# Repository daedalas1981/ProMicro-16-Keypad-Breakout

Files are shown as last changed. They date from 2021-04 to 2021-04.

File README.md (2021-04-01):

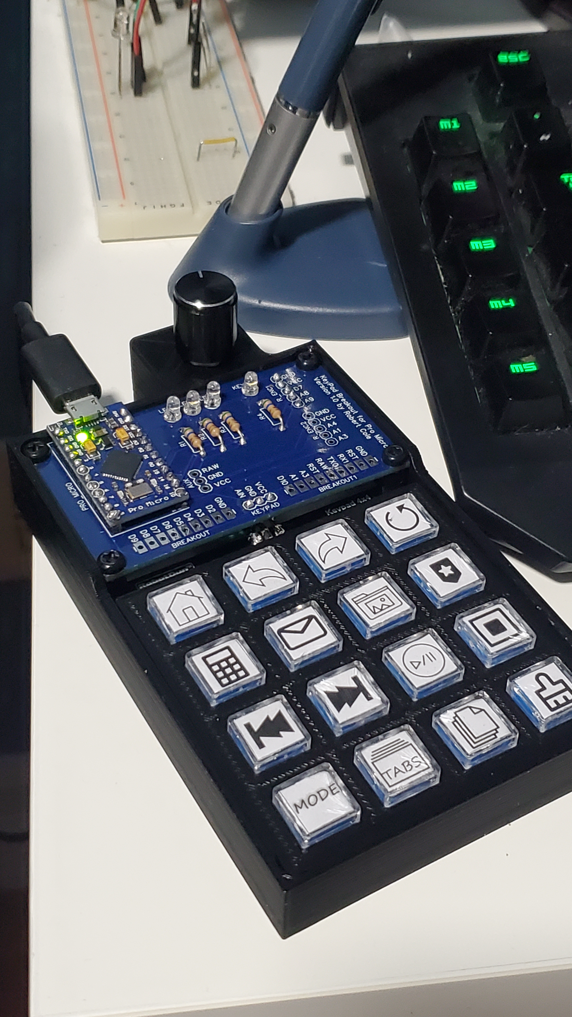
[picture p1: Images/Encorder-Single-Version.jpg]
Single Encoder
**Single Encoder**  or **Dual Encoder** Dual Encoder
# KeyPad Breakout for Pro Micro and RobotDyn Keypad
## Required components:
- Arduino Pro Micro 32U Microcontroller.
- NicoHood's HID-Project Library for Arduino. [HID-Project](https://github.com/NicoHood/HID)
- RobotDyn 16 button 3-wire keypad. [RobotDyn 4x4 Keypad](https://robotdyn.com/button-keypad-4x4-module.html) / [Banggood - RobotDyn 4x4 Keypad](https://www.banggood.com/5V-Button-Keypad-4x4-Module-Assembled-Keyboard-p-1645007.html)
- Keypad Breakout for Pro Micro ver1.0 by Robert.
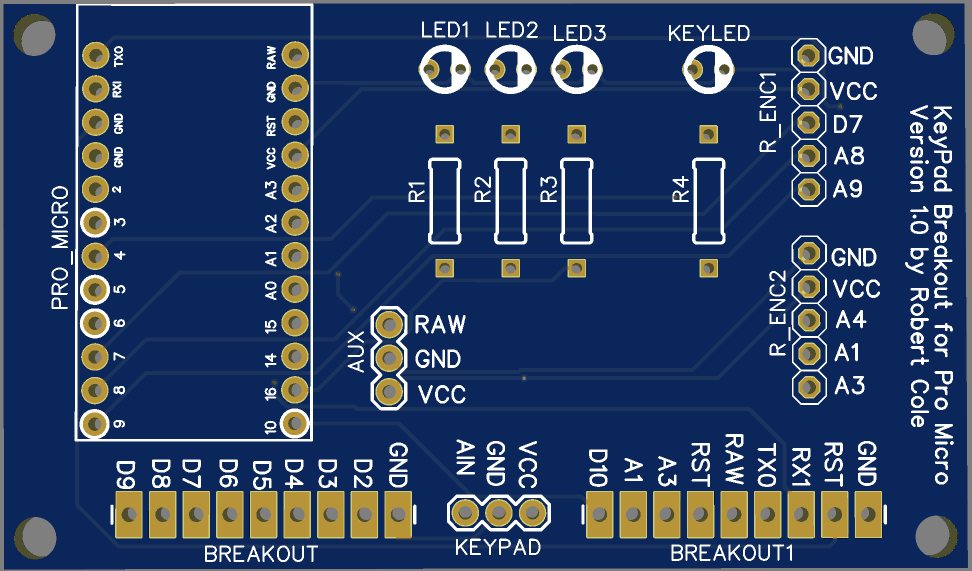
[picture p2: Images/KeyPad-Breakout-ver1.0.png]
KeyPad Breakout


## Optional (but recommended):
- One or Two Dual Encoders with presoldered resistors. [Amazon - Cylewet 5Pcs KY-040 Rotary Encoder Module with 15×16.5 mm with Knob Cap for Arduino](https://www.amazon.ca/dp/B07DFFSZ73/ref=cm_sw_em_r_mt_dp_GTFJT82QA5BB0PV9Z99V?_encoding=UTF8&psc=1)
- (4) 3mm LEDS. (I used white generic. Will determine resistors req'd).
- (4) 5.6ohm resistors. (or appropriate  for your LEDS).
- Male to Female Leads.
- 3D Printed Case. (or maybe a suitable wood case?).
- Printer / Printed labels for the keypad.
- (6) M3 Screws and Nuts. [Screws / Nuts / Standoffs](https://www.amazon.ca/gp/product/B06Y591NKK/ref=ppx_yo_dt_b_asin_title_o04_s01?ie=UTF8&psc=1)
- (2) M3 x 8mm Standoffs.

## Folder Structure
- **Arduino**, contains .INO for Arduino IDE. Requires HID-Project.h Library (GitHub) and Encoder.h (Library Manager in IDE)
- **EasyEDA**, contains .JSON files for EasyEDA to create PCB for the breakout board. Can be sent to board manufacturer.
- **Fusion360**, contains both .F3D and .STL files. The .F3D files can be changed to your neeeds. The .STL can be sent to a 3D printed if using the same components.
- **Images**, Self-explanatory.
- **KeyMap**, contains a text file with the default key mapping when using the configured settings in the .INO file for Arduino. I use it as a cheat sheet.
- **RobotDyn**, contains files for measurements and schematics for the keypad.
- **Schematics**, contains all the diagrams, pictures, and schematics of the project.

# Description
I wanted to turn a keypad into a functional macro keyboard. In order to maximize the use of the keyboard, I created a MODE button that allows up to 4 button layouts that can be toggled between. Using the HID-Project Library, the first mode focuses on common shortcuts, web broswers, and operating systems. MODES 2-4 focus on the use of F13-F24 keys not normally found on standard keyboards allowing unique bindings for different applications.

One of the best features is pairing this project with one or two encoders. I have programmed them by default as being one dedicated to Volume Up and Down with the press to Mute. The second encoder has been set to be a Zoom In and Out with the press to Reset to 100%. Perfect for Photoshop, or even Web browsing,

**Noteworthy code for the encoders:** 4x4-KeyPad-Multi.ino
```
// ENCODER SETUP
bool encoderOneEnable = true; // DEFAULT ENCODER on R_ENC1
bool encoderTwoEnable = true; // SECONDARY ENCODER on R_ENC2
```
*These settings will enable or disable the encoders.*

I also left many pin outs for possible future use or variations when designing the circuit board. As of version 1.0, I can say everything is working! However, like everything when prototyping, I should have chose my pins more wisely for the LEDs. It would have been nice to set a dimmer for them. Three of the LEDs display the Mode. All off is mode 1, left LED is mode 2, middle LED is mode 3, and the right LED is mode 4. They all stay on while in their respective mode. The fourth LED is a keypress confirmation. Briefly lights while the key is pressed, and turns off when released.

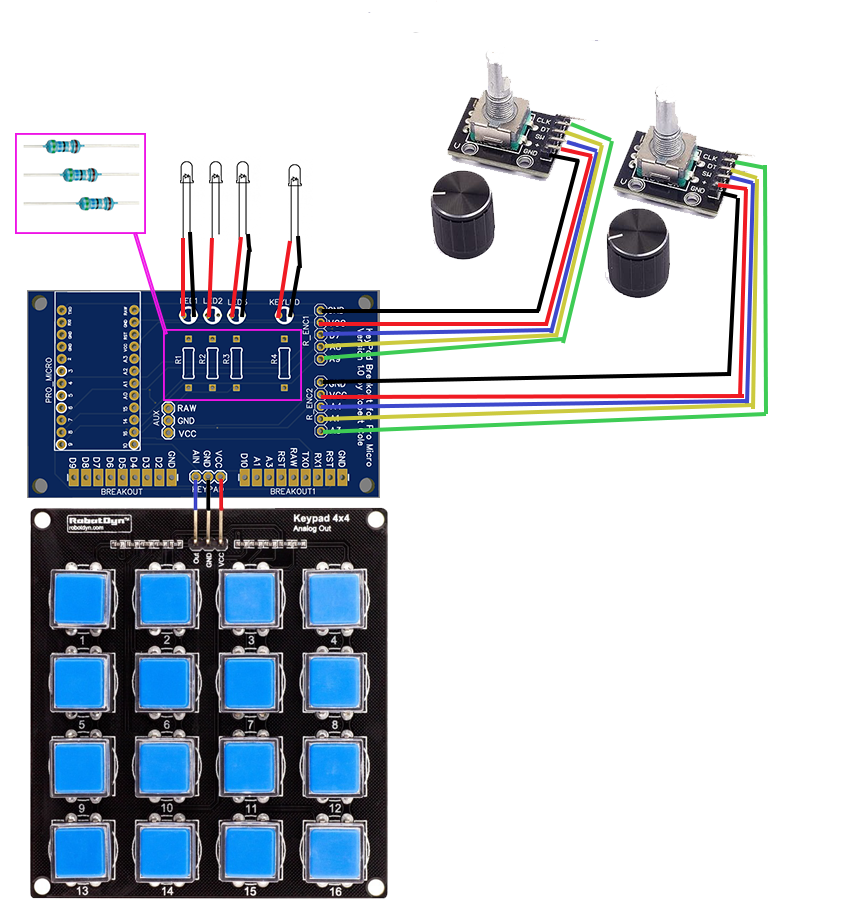
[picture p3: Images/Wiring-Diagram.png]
Wiring Diagram


# Friendly Words
This is my first public project. I'm fairly new to creating content on GitHub. I have been programming for awhile. The project case I created using Fusion 360, and printed on an AnyCubic Mega Pro. The circuit board was created using EasyEDA. It was the first time I created a circuit board and had it printed via PCBWay as they do small batches for cheap at the time of writing this. Many thanks to snippets of code and hours of mistakes to get the code to where it is today from countless people I found on internet searches. NicoHood's HID-Project was the final touch required to make this project possible. Please leave me a comment if something is not right, or can be changed, or if I've done something wrong. Thanks!

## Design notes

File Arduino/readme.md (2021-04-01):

# Arduino

## Arduino Pro Micro Version
In order for the RobotDyn 4x4 KeyPad to read the values from the analog output, the 5V-16 MHz version of the board must be used.

## Arduino Pro Micro Leonardo
The firmware / IDE settings need to be the Leonardo. This is so the device can broadcast itself over USB as a HID device. (Human Interface Device). It will show up in Windows as a Leonardo USB HID Device.

## Arduino IDE / INO
Please note the SETUP for the Encoders. Change as needed for One or Two.
```
// ENCODER SETUP
bool encoderOneEnable = true; // DEFAULT ENCODER on R_ENC1
bool encoderTwoEnable = true; // SECONDARY ENCODER on R_ENC2
```
Also the pinouts are set for use with the breakout board. Change what suits your needs.

## Key Mapping
The .INO file is broken into 4 CASES. Each Case has 16 key mappings.
- Case 0 - 15 Keys + 1 Mode Key - Mode 1 - Default - System Macros
- Case 1 - 15 Keys + 1 Mode Key - Mode 2 -  Unique Left Control + F13-F24 Keys + Copy / Paste
- Case 2 - 15 Keys + 1 Mode Key - Mode 3 -  F13-F24 Keys + Copy / Paste
- Case 3 - 15 Keys + 1 Mode Key - Mode 4 -  F1-F12 Keys + Save/Close/Quit

Create combinations of KeyPresses, but just remember to release them again!
```
KeyPress.releaseALL();
```

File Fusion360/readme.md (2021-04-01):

# Single vs Dual Encoder
I found using dual encoders to help with many of the projects I was working on. A single encoder is great for volume up and down.

## Some Ideas for a 2nd Encoder
- Microphone Volume up and down / Press to Mute. (Custom Mapping req'd.)
- Zoom In and Out / Press to Reset. (Ctrl+, Ctrl-, Ctrl 0)
- Scroll Up and Down / Press to Home or End. (Page Up, Page Down, Home/End)
- Scrub Left and Right / Press Enter. (Left arrow, Right arrow, Enter)
- Add/Subtract Values / Press to Enter. ((+1 Enter),(-1 Enter), Enter) <- Using 1 as an increment example.
- Fast Forward / Rewind / Play/Pause. (FF,Rewind,Play/Pause)
- Cycle thru Open Windows / Press to Open.
- Cycle thru Browser Tabs.
- Use the 2nd Encoder Press for Mode Switching allowing an addtional key (Key 13) for assignment.

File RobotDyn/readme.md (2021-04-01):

Using Photoshop you can change or create your own printable Icons. The Squares are 11.8mm x 11.8mm. I created them at 12mm x 12mm and cut the black line so that it was not visible and fit perfectly in the clear key caps.

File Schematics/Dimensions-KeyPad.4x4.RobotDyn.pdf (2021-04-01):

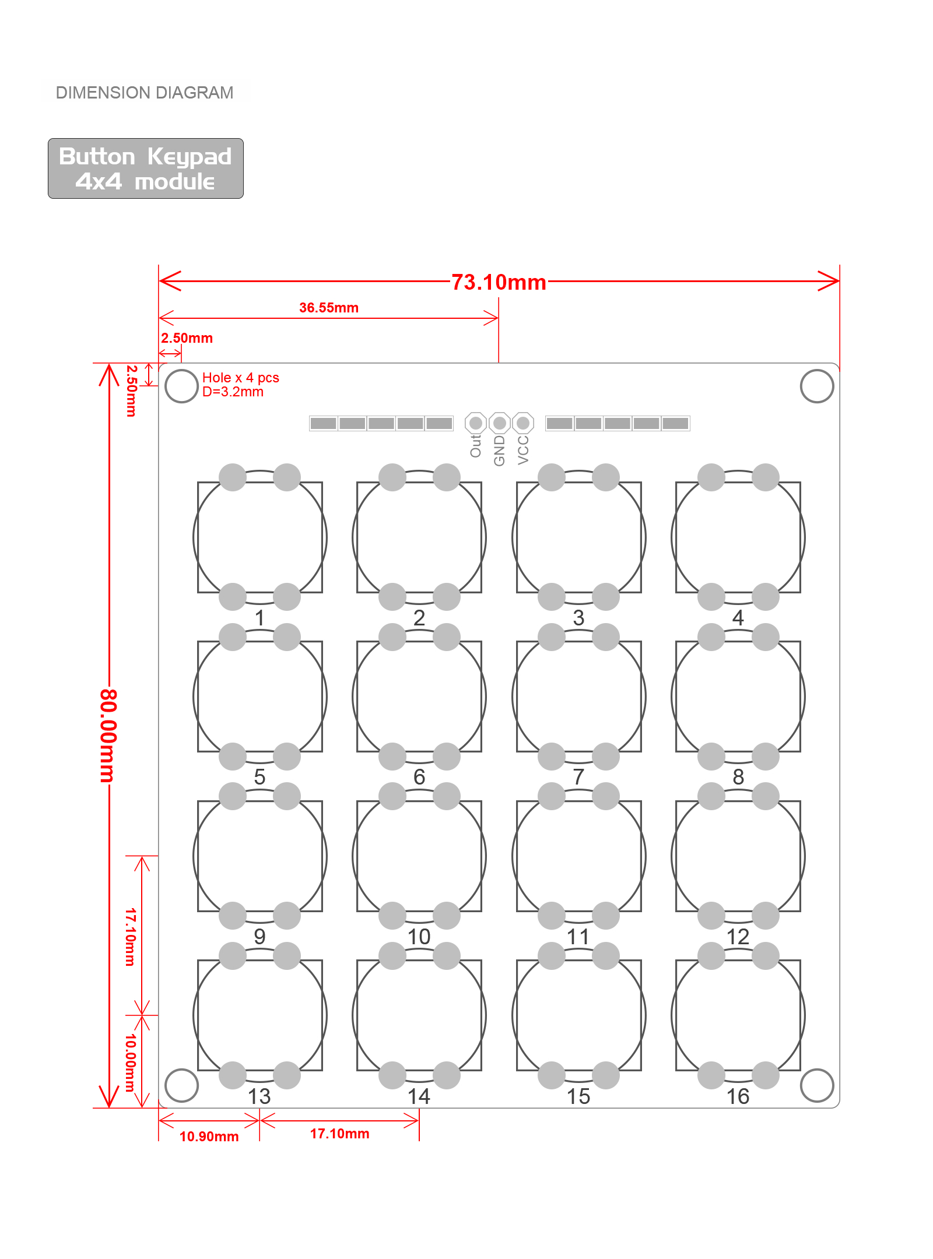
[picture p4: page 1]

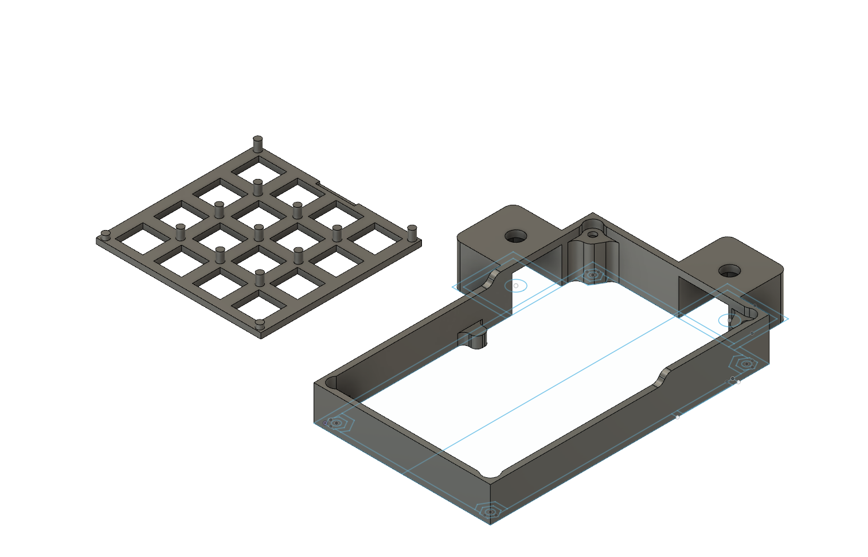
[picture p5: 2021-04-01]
Schematics/DUAL Encoder v1.png

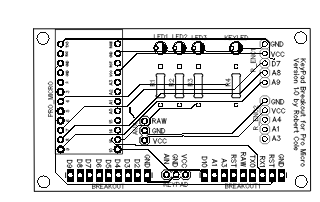
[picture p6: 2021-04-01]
Schematics/PCB_Layout-Keypad.Breakout.ver1.0.png

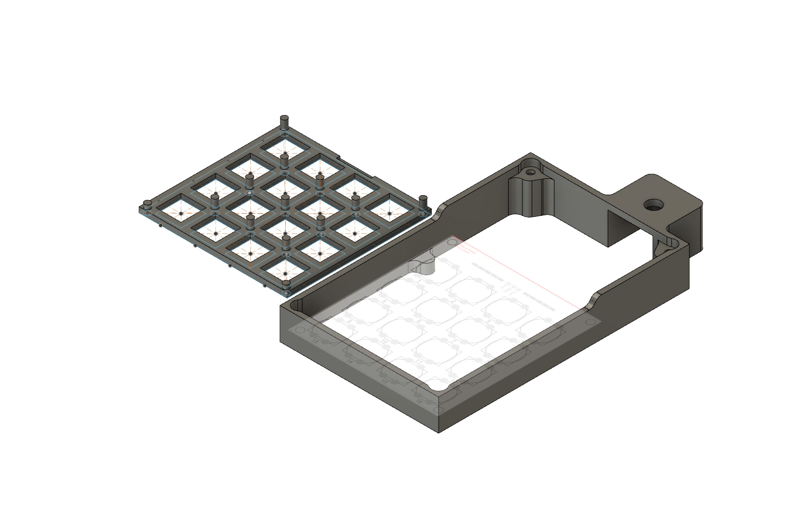
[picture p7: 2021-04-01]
Schematics/Single Encoder.png

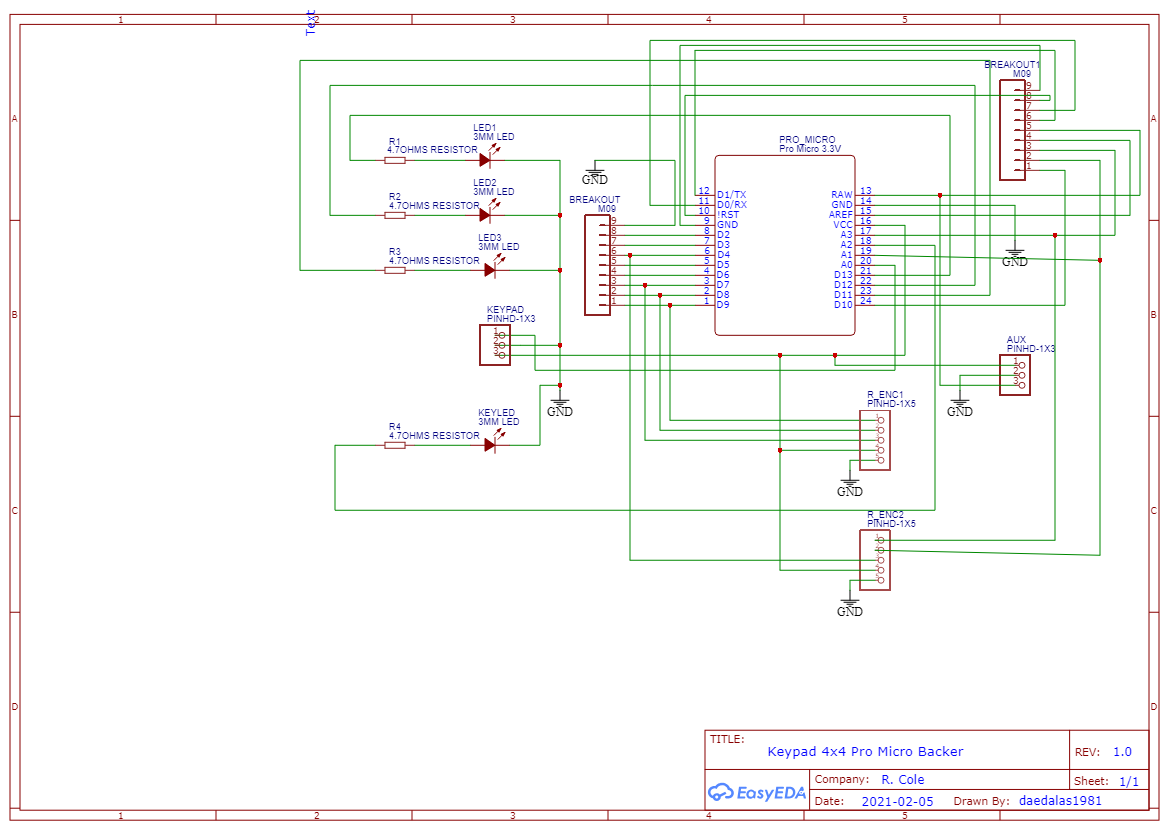
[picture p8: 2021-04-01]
Schematics/Schematic_4x4 Keypad_2021-03-31.png

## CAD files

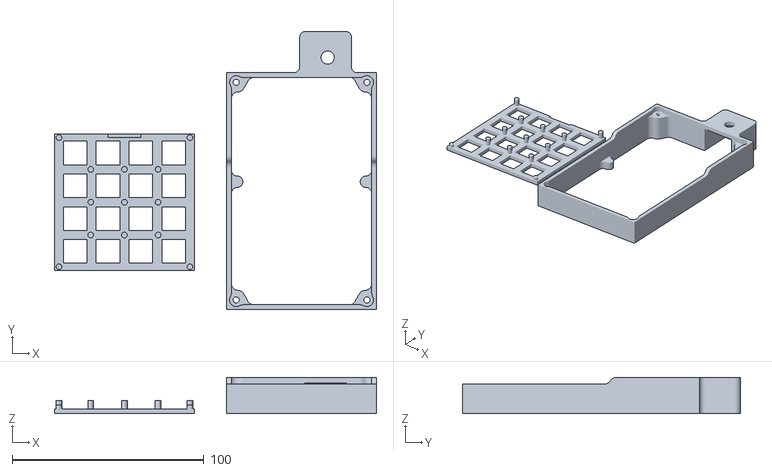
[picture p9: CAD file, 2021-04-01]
Fusion360/Single Encoder.stl
167.8 x 144.9 x 19.0

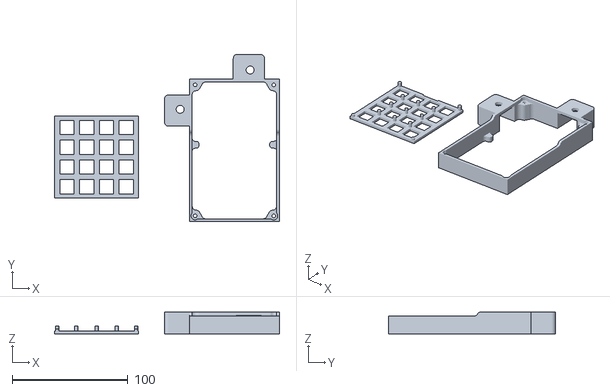
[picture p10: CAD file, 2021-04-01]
Fusion360/DUAL Encoder.stl
194.8 x 144.9 x 19.0

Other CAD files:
Fusion360/DUAL Encoder.f3d
Fusion360/SINGLE Encoder.f3d

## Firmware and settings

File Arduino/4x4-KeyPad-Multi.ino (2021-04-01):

///////////////////////////////////////////////
// RobotDyn Keypad 4x4 Macro Script ver1.0  //
/********************************************
// Arduino Pro Micro
// 3-Wire Connection
// ~ Data Pin on A0
// ~ Power 5V on VCC
// ~ Ground on GND
//
// KeyPad Breakout for Pro Micro v1.0 by Robert Cole
***********************************/
// Created by Robert Cole

// KEY REFERENCE GUIDE
/*
KEY_LEFT_CTRL
KEY_LEFT_SHIFT
KEY_LEFT_ALT
KEY_LEFT_GUI
KEY_RIGHT_CTRL
KEY_RIGHT_SHIFT
KEY_RIGHT_ALT
KEY_RIGHT_GUI
KEY_UP_ARROW
KEY_DOWN_ARROW
KEY_LEFT_ARROW
KEY_RIGHT_ARROW
KEY_BACKSPACE
KEY_TAB
KEY_RETURN
KEY_ESC
KEY_INSERT
KEY_DELETE
KEY_PAGE_UP
KEY_PAGE_DOWN
KEY_HOME
KEY_END
KEY_CAPS_LOCK
KEY_F1
KEY_F2
KEY_F3
KEY_F4
KEY_F5
KEY_F6
KEY_F7
KEY_F8
KEY_F9
KEY_F10
KEY_F11
KEY_F12
KEY_F13
KEY_F14
KEY_F15
KEY_F16
KEY_F17
KEY_F18
KEY_F19
KEY_F20
KEY_F21
KEY_F22
KEY_F23
KEY_F24

*** CONSUMER.WRITE KEY LIST ***

MEDIA_FAST_FORWARD
MEDIA_REWIND
MEDIA_NEXT
MEDIA_PREVIOUS
MEDIA_STOP
MEDIA_PLAY_PAUSE

MEDIA_VOLUME_MUTE
MEDIA_VOLUME_UP
MEDIA_VOLUME_DOWN

CONSUMER_EMAIL_READER
CONSUMER_CALCULATOR
CONSUMER_EXPLORER

CONSUMER_BROWSER_HOME
CONSUMER_BROWSER_BACK
CONSUMER_BROWSER_FORWARD
CONSUMER_BROWSER_REFRESH
CONSUMER_BROWSER_BOOKMARKS

*/

// Include HID-Project by NicoHood - Keyboard Library
#include <HID-Project.h>

// Include Encorder Library
#include <Encoder.h>

// Analog Data Pin = Pin A0 or Pin 18 FOR RobotDyn 4x4 (3-wire) KEYPAD / AIN->OUT
const int buttonPin = A0;

// On Press Button Flash LED
const int flashLED = A2;

// LED MODE Indicator Pins
const int MODE1 = 15;
const int MODE2 = 14;
const int MODE3 = 16;
int  currentMode = 0;

// ENCODER SETUP
bool encoderOneEnable = true; // DEFAULT ENCODER on R_ENC1
bool encoderTwoEnable = true; // SECONDARY ENCODER on R_ENC2

// ENCODER 1 SETUP
const int buttonMute = 7; // MUTE BUTTON / Switch Pin

Encoder knobVol(8, 9);  // VOLUME KNOB

int stateVol = 0;
long volValue  = -999;

// ENCODER 2 SETUP
const int buttonMuteTWO = 4; // MUTE BUTTON / Switch Pin

Encoder knobVolTWO(19, 21);  // VOLUME KNOB / Second Encoder

int stateVolTWO = 0;
long volValueTWO  = -999; 

// Get KeyPaD Analog Value
int get_button(int val) {
 // Lets get the Current Mode to Decide Which Macro Layout to Use
 switch(currentMode){
 // DEFAULT LAYOUT
 
 // MODE 1 SETUP ******************************************
 case 0:
  // get analog input value
 if(val>1000){
    Consumer.write(CONSUMER_BROWSER_HOME);
    delay(200);
    return 1;
 }
 else if(val>900){
    Consumer.write(CONSUMER_BROWSER_BACK);
    delay(200);
    return 2;
 }
 else if(val>820){
    Consumer.write(CONSUMER_BROWSER_FORWARD);
    delay(200);
    Keyboard.releaseAll();
    return 3;
 }
 else if(val>750){
    Consumer.write(CONSUMER_BROWSER_REFRESH);
    delay(200);
    return 4;
 }
 else if(val>660){
    Consumer.write(CONSUMER_CALCULATOR);
    delay(200);
    return 5;
 }
 else if(val>620){
    Consumer.write(CONSUMER_EMAIL_READER);
    delay(200);
    return 6;
 }
 else if(val>585){
    Consumer.write(CONSUMER_EXPLORER);
    delay(200);
    return 7;
 }
 else if(val>540){
    Keyboard.press(KEY_LEFT_CTRL); //Presses the CTRL key.
    Keyboard.press(KEY_LEFT_SHIFT); //Presses the CTRL key.
    Keyboard.press('o'); //Presses the F16 key.
    delay(200);
    Keyboard.releaseAll();
    return 8;
 }
 else if(val>500){
    Consumer.write(MEDIA_PREVIOUS);
    delay(200);
    return 9;
 }
 else if(val>475){
    Consumer.write(MEDIA_NEXT);
    delay(200);
    return 10;
 }
 else if(val>455){
    Consumer.write(MEDIA_PLAY_PAUSE);
    delay(200);
    return 11;
 }
 else if(val>425){
    Consumer.write(MEDIA_STOP);
    delay(200);
    return 12;
 }
 else if(val>370){
    // Switch Mode Button on 13
    // Add 1 to the Current Mode
    currentMode++;
    if (currentMode == 4) {
      // RESET to 0 when MAX. 
      currentMode = 0;
    }
    switch_Mode(currentMode);
    delay(200);
    Keyboard.releaseAll();
    return 13;
 }
 else if(val>300){
    // Change TAB View
    Keyboard.press(KEY_LEFT_ALT); //Presses the LEFT ALT key.
    Keyboard.press(KEY_TAB); //Presses the TAB key.
    Keyboard.release(KEY_TAB); // Release Single Keypress.
    Keyboard.press(KEY_TAB); //Presses the TAB key.
    delay(200);
    Keyboard.releaseAll();
    return 14;
 }
 else if(val>260){
    // COPY
    Keyboard.press(KEY_LEFT_CTRL); //Presses the CTRL key.
    Keyboard.press('c'); //Presses the C key.
    delay(200);
    Keyboard.releaseAll();
    return 15;
 }
 else if(val>200){
    // PASTE
    Keyboard.press(KEY_LEFT_CTRL); //Presses the CTRL key.
    Keyboard.press('v'); //Presses the C key.
    delay(200);
    Keyboard.releaseAll();
    return 16;
 }
 else {
    return 0;
 }
    break;

// MODE 2 SETUP ******************************************   
 case 1:
 // get analog input value
 if(val>1000){
    Keyboard.press(KEY_LEFT_CTRL); //Presses the CTRL key.
    Keyboard.press(KEY_F13); //Presses the F13 key.
    delay(200);
    Keyboard.releaseAll();
    return 1;
 }
 else if(val>900){
    Keyboard.press(KEY_LEFT_CTRL); //Presses the CTRL key.
    Keyboard.press(KEY_F14); //Presses the F14 key.
    delay(200);
    Keyboard.releaseAll();
    return 2;
 }
 else if(val>820){
    Keyboard.press(KEY_LEFT_CTRL); //Presses the CTRL key.
    Keyboard.press(KEY_F15); //Presses the F15 key.
    delay(200);
    Keyboard.releaseAll();
    return 3;
 }
 else if(val>750){
    Keyboard.press(KEY_LEFT_CTRL); //Presses the CTRL key.
    Keyboard.press(KEY_F16); //Presses the F16 key.
    delay(200);
    Keyboard.releaseAll();
    return 4;
 }
 else if(val>660){
    Keyboard.press(KEY_LEFT_CTRL); //Presses the CTRL key.
    Keyboard.press(KEY_F17); //Presses the F17 key.
    delay(200);
    Keyboard.releaseAll();
    return 5;
 }
 else if(val>620){
    Keyboard.press(KEY_LEFT_CTRL); //Presses the CTRL key.
    Keyboard.press(KEY_F18); //Presses the F18 key.
    delay(200);
    Keyboard.releaseAll();
    return 6;
 }
 else if(val>585){
    Keyboard.press(KEY_LEFT_CTRL); //Presses the CTRL key.
    Keyboard.press(KEY_F19); //Presses the F19 key.
    delay(200);
    Keyboard.releaseAll();
    return 7;
 }
 else if(val>540){
    Keyboard.press(KEY_LEFT_CTRL); //Presses the CTRL key.
    Keyboard.press(KEY_F20); //Presses the F20 key.
    delay(200);
    Keyboard.releaseAll();
    return 8;
 }
 else if(val>500){
    Keyboard.press(KEY_LEFT_CTRL); //Presses the CTRL key.
    Keyboard.press(KEY_F21); //Presses the F21 key.
    delay(200);
    Keyboard.releaseAll();
    return 9;
 }
 else if(val>475){
    Keyboard.press(KEY_LEFT_CTRL); //Presses the CTRL key.
    Keyboard.press(KEY_F22); //Presses the F22 key.
    delay(200);
    Keyboard.releaseAll();
    return 10;
 }
 else if(val>455){
    Keyboard.press(KEY_LEFT_CTRL); //Presses the CTRL key.
    Keyboard.press(KEY_F23); //Presses the F23 key.
    delay(200);
    Keyboard.releaseAll();
    return 11;
 }
 else if(val>425){
    Keyboard.press(KEY_LEFT_CTRL); //Presses the CTRL key.
    Keyboard.press(KEY_F24); //Presses the F24 key.
    delay(200);
    Keyboard.releaseAll();
    return 12;
 }
 else if(val>370){
    // Switch Mode Button on 13
    // Add 1 to the Current Mode
    currentMode++;
    if (currentMode == 4) {
      // RESET to 0 when MAX. 
      currentMode = 0;
    }
    switch_Mode(currentMode);
    delay(200);
    Keyboard.releaseAll();
    return 13;
 }
 else if(val>300){
    // Change TAB View
    Keyboard.press(KEY_LEFT_ALT); //Presses the LEFT ALT key.
    Keyboard.press(KEY_TAB); //Presses the TAB key.
    Keyboard.release(KEY_TAB); // Release Single Keypress.
    Keyboard.press(KEY_TAB); //Presses the TAB key.
    delay(200);
    Keyboard.releaseAll();
    return 14;
 }
 else if(val>260){
    // COPY
    Keyboard.press(KEY_LEFT_CTRL); //Presses the CTRL key.
    Keyboard.press('c'); //Presses the C key.
    delay(200);
    Keyboard.releaseAll();
    return 15;
 }
 else if(val>200){
    // PASTE
    Keyboard.press(KEY_LEFT_CTRL); //Presses the CTRL key.
    Keyboard.press('v'); //Presses the C key.
    delay(200);
    Keyboard.releaseAll();
    return 16;
 }
 else {
    return 0;
 }
    break;
 
 // MODE3 SETUP ******************************************
  case 2:
  // ALTERNATE MODE 2
  // get analog input value
 if(val>1000){
    Keyboard.press(KEY_F13); //Presses the F13 key.
    delay(200);
    Keyboard.releaseAll();
    return 1;
 }
 else if(val>900){
    Keyboard.press(KEY_F14); //Presses the F14 key.
    delay(200);
    Keyboard.releaseAll();
    return 2;
 }
 else if(val>820){
    Keyboard.press(KEY_F15); //Presses the F15 key.
    delay(200);
    Keyboard.releaseAll();
    return 3;
 }
 else if(val>750){
    Keyboard.press(KEY_F16); //Presses the F16 key.
    delay(200);
    Keyboard.releaseAll();
    return 4;
 }
 else if(val>660){
    Keyboard.press(KEY_F17); //Presses the F17 key.
    delay(200);
    Keyboard.releaseAll();
    return 5;
 }
 else if(val>620){
    Keyboard.press(KEY_F18); //Presses the F18 key.
    delay(200);
    Keyboard.releaseAll();
    return 6;
 }
 else if(val>585){
    Keyboard.press(KEY_F19); //Presses the F19 key.
    delay(200);
    Keyboard.releaseAll();
    return 7;
 }
 else if(val>540){
    Keyboard.press(KEY_F20); //Presses the F20 key.
    delay(200);
    Keyboard.releaseAll();
    return 8;
 }
 else if(val>500){
    Keyboard.press(KEY_F21); //Presses the F21 key.
    delay(200);
    Keyboard.releaseAll();
    return 9;
 }
 else if(val>475){
    Keyboard.press(KEY_F22); //Presses the F22 key.
    delay(200);
    Keyboard.releaseAll();
    return 10;
 }
 else if(val>455){
    Keyboard.press(KEY_F23); //Presses the F23 key.
    delay(200);
    Keyboard.releaseAll();
    return 11;
 }
 else if(val>425){
    Keyboard.press(KEY_F24); //Presses the F24 key.
    delay(200);
    Keyboard.releaseAll();
    return 12;
 }
 else if(val>370){
    // Switch Mode Button on 13
    // Add 1 to the Current Mode
    currentMode++;
    if (currentMode == 4) {
      // RESET to 0 when MAX. 
      currentMode = 0;
    }
    switch_Mode(currentMode);
    delay(200);
    Keyboard.releaseAll();
    return 13;
 }
 else if(val>300){
    // Change TAB View
    Keyboard.press(KEY_LEFT_ALT); //Presses the LEFT ALT key.
    Keyboard.press(KEY_TAB); //Presses the TAB key.
    Keyboard.release(KEY_TAB); // Release Single Keypress.
    Keyboard.press(KEY_TAB); //Presses the TAB key.
    delay(200);
    Keyboard.releaseAll();
    return 14;
 }
 else if(val>260){
    // COPY
    Keyboard.press(KEY_LEFT_CTRL); //Presses the CTRL key.
    Keyboard.press('c'); //Presses the C key.
    delay(200);
    Keyboard.releaseAll();
    return 15;
 }
 else if(val>200){
    // PASTE
    Keyboard.press(KEY_LEFT_CTRL); //Presses the CTRL key.
    Keyboard.press('v'); //Presses the C key.
    delay(200);
    Keyboard.releaseAll();
    return 16;
 }
 else {
    return 0;
 }
    break;

 // MODE 4 SETUP ******************************************
  case 3:
  // ALTERNATE MODE 3
  // get analog input value
 if(val>1000){
    Keyboard.press(KEY_F1); //Presses the F13 key.
    delay(200);
    Keyboard.releaseAll();
    return 1;
 }
 else if(val>900){
    Keyboard.press(KEY_F2); //Presses the F14 key.
    delay(200);
    Keyboard.releaseAll();
    return 2;
 }
 else if(val>820){
    Keyboard.press(KEY_F3); //Presses the F15 key.
    delay(200);
    Keyboard.releaseAll();
    return 3;
 }
 else if(val>750){
    Keyboard.press(KEY_F4); //Presses the F16 key.
    delay(200);
    Keyboard.releaseAll();
    return 4;
 }
 else if(val>660){
    Keyboard.press(KEY_F5); //Presses the F17 key.
    delay(200);
    Keyboard.releaseAll();
    return 5;
 }
 else if(val>620){
    Keyboard.press(KEY_F6); //Presses the F18 key.
    delay(200);
    Keyboard.releaseAll();
    return 6;
 }
 else if(val>585){
    Keyboard.press(KEY_F7); //Presses the F19 key.
    delay(200);
    Keyboard.releaseAll();
    return 7;
 }
 else if(val>540){
    Keyboard.press(KEY_F8); //Presses the F20 key.
    delay(200);
    Keyboard.releaseAll();
    return 8;
 }
 else if(val>500){
    Keyboard.press(KEY_F9); //Presses the F21 key.
    delay(200);
    Keyboard.releaseAll();
    return 9;
 }
 else if(val>475){
    Keyboard.press(KEY_F10); //Presses the F22 key.
    delay(200);
    Keyboard.releaseAll();
    return 10;
 }
 else if(val>455){
    Keyboard.press(KEY_F11); //Presses the F23 key.
    delay(200);
    Keyboard.releaseAll();
    return 11;
 }
 else if(val>425){
    Keyboard.press(KEY_F12); //Presses the F24 key.
    delay(200);
    Keyboard.releaseAll();
    return 12;
 }
 else if(val>370){
    // Switch Mode Button on 13
    // Add 1 to the Current Mode
    currentMode++;
    if (currentMode == 4) {
      // RESET to 0 when MAX. 
      currentMode = 0;
    }
    switch_Mode(currentMode);
    delay(200);
    Keyboard.releaseAll();
    return 13;
 }
 else if(val>300){
    // SAVE BUTTON
    Keyboard.press(KEY_LEFT_CTRL); //Presses the CTRL key.
    Keyboard.press('s'); //Presses the C key.
    delay(200);
    Keyboard.releaseAll();
    return 14;
 }
 else if(val>260){
    // CLOSE CURRENT WINDOW WITHIN APPLICATION
    Keyboard.press(KEY_LEFT_CTRL); //Presses the CTRL key.
    Keyboard.press('w'); //Presses the C key.
    delay(200);
    Keyboard.releaseAll();
    return 15;
 }
 else if(val>200){
    // QUIT PROGRAM
    Keyboard.press(KEY_LEFT_CTRL); //Presses the CTRL key.
    Keyboard.press('q'); //Presses the C key.
    delay(200);
    Keyboard.releaseAll();
    return 16;
 }
 else {
    return 0;
 }
    break;
 }
  
}


// SET THE LED PINS BASED ON CURRENT MODE SELECTED
int switch_Mode(int mInt) {
  switch(mInt) {
    case 1:
    digitalWrite(MODE1, HIGH);
    digitalWrite(MODE2, LOW);
    digitalWrite(MODE3, LOW);
    currentMode = 1;
    Serial.println("Mode 1 Enabled");
    break;

    case 2:
    digitalWrite(MODE1, LOW);
    digitalWrite(MODE2, HIGH);
    digitalWrite(MODE3, LOW);
    currentMode = 2;
    Serial.println("Mode 2 Enabled");
    break;

    case 3:
    digitalWrite(MODE1, LOW);
    digitalWrite(MODE2, LOW);
    digitalWrite(MODE3, HIGH);
    currentMode = 3;
    Serial.println("Mode 3 Enabled");
    break;

    default:
    digitalWrite(MODE1, LOW);
    digitalWrite(MODE2, LOW);
    digitalWrite(MODE3, LOW);
    currentMode = 0;
    Serial.println("Default Mode Enabled");
    break;
  }
}

void setup() {
  // Keyboard Init
  Keyboard.begin();
  Consumer.begin();
  
  // Serial Port Init
  Serial.begin(9600);

  // Set LED Mode Indicators as OUTPUTs
  pinMode(MODE1, OUTPUT);
  pinMode(MODE2, OUTPUT);
  pinMode(MODE3, OUTPUT);

  // Delay Setup, wait for Init's
  delay(200);
}

void loop() {
 
 // Get value of analog input on Keypad
 int valueA1=analogRead(buttonPin);
 
 // Output data to serial port
 if (valueA1 > 100) {
  // Detected Button Press, now Flash LED & Brightness 1023 except MODE SWITCH
  if ((valueA1>370) && (valueA1<425)){analogWrite(flashLED, 0);} else {analogWrite(flashLED, 1023);} 
  // Which Button was Pressed?
  int pressedBtn = get_button(valueA1);
  // Write Findings to Serial
  Serial.println(valueA1);
  Serial.println(pressedBtn);   
 delay(150);
 // TURN OFF BUTTON PRESS LED REGARDLESS OF STATE / Brightness 0
 analogWrite(flashLED, 0);
 }
 
 // ENCCODER 1 SETUP
 if (encoderOneEnable == true) {
 /* Simple button press for knob momentary switch */
    stateVol = digitalRead(buttonMute) == LOW;
    if (stateVol == HIGH) {
      Consumer.write(MEDIA_VOLUME_MUTE);
      analogWrite(flashLED, 1023);
      Serial.println("ENCODER 1 Button Pressed!");
      delay(200);
      analogWrite(flashLED, 0);
    }

  /* React to changes of encoder */
    long newVolValue;  
    newVolValue = knobVol.read();
    if (newVolValue != volValue) { // Changed position
      if (newVolValue > volValue) { // Right turn
        Consumer.write(MEDIA_VOLUME_UP);
        Serial.println(knobVol.read());
      } else if (newVolValue < volValue) { // Left turn
        Consumer.write(MEDIA_VOLUME_DOWN);
        Serial.println(knobVol.read());
      }
      volValue = newVolValue;
    } }

// ENCCODER 2 SETUP
if (encoderTwoEnable == true) {
 /* Simple button press for knob momentary switch */
    stateVolTWO = digitalRead(buttonMuteTWO) == LOW;
    if (stateVolTWO == HIGH) {
      Keyboard.press(KEY_LEFT_CTRL); //Presses the CTRL key.
      Keyboard.press('0'); //Reset Zoom Shortcut.
      Keyboard.releaseAll();
      analogWrite(flashLED, 1023);
      Serial.println("ENCODER 2 Button Pressed!");
      delay(200);
      analogWrite(flashLED, 0);
    }

  /* React to changes of encoder */
    long newVolValueTWO;  
    newVolValueTWO = knobVolTWO.read();
    if (newVolValueTWO != volValueTWO) { // Changed position
      if (newVolValueTWO > volValueTWO) { // Right turn
        Keyboard.press(KEY_LEFT_CTRL); //Presses the CTRL key.
        Keyboard.press('+'); //Presses the Zoom In key.
        Keyboard.releaseAll();
        Serial.println(knobVolTWO.read());
      } else if (newVolValueTWO < volValueTWO) { // Left turn
        Keyboard.press(KEY_LEFT_CTRL); //Presses the CTRL key.
        Keyboard.press('-'); //Presses the Zoom Out key.
        Keyboard.releaseAll();
        Serial.println(knobVolTWO.read());
      }
      volValueTWO = newVolValueTWO;
    } }
    
}
